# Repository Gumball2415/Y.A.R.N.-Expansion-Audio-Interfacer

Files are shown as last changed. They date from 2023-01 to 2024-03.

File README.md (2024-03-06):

# Y.A.R.N. Expansion Audio Interfacer

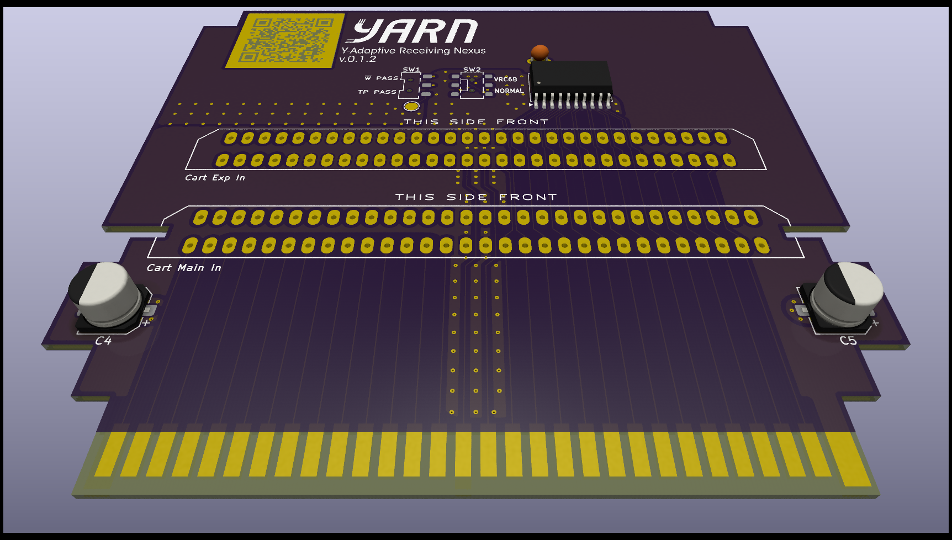
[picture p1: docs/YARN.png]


An Open-Source HardWare (OSHW) Famicom single expansion audio interfacer.

## About

This project aims to allow a host cartridge to control an expansion audio cartridge's sound chip through selected audio registers. This is a child of the S.C.A.R.F. project.

The principle is that the Main cartridge is expected to contain everything the NSF or program needs, with the audio solely being handled by the Exp audio cartridge.

This means that the expansion audio cartridge is write-only.

## Use

The Main cartridge is expected to contain mapper hardware that the NSF or program needs.

The Console is expected to not read the Exp. cartridge, but instead to write to registers the Exp. cartridge is expected to contain.

The Exp. cartridge must contain hardware that generates audio accessible by write-only registers that the Console expects.

If the Exp. cartridge contains VRC6B, toggle SW2 accordingly.

Do not toggle SW1, it is for prototyping purposes.

For Everdrives and flash carts: The flash cart UI (if it has one) may cause unwanted side effects if it is connected to YARN.

## PCB Specifications

- 2 layer PCB
- 1.2mm thickness
- ENIG-RoHS surface finish recommended; Gold fingers optional
- Beveled edge, chamfer cut
- Any soldermask color you want!

## License

- The PCB and schematics are licensed under the TAPR Open Hardware License ([www.tapr.org/OHL](http://www.tapr.org/OHL)).
- The S.C.A.R.F. Expansion Audio Interfacer Address Decoder ROM source code file is licensed under [MIT](https://mit-license.org/)
- © Persune 2022

## Credits

- lidnariq, grievre, Iyatemu, and plgDavid - advice, suggestions, general help
- lidnariq - providing advice for my schematics and addressing logic
- grievre - providing advice for my PCB design
- Special thanks to the NESDEV community, this project wouldn't have been possible without their extensive information and wiki!

## Support

If you enjoy this project or find it helpful, please support me on [Ko-Fi](https://ko-fi.com/persune) or [Patreon](https://www.patreon.com/persune)!

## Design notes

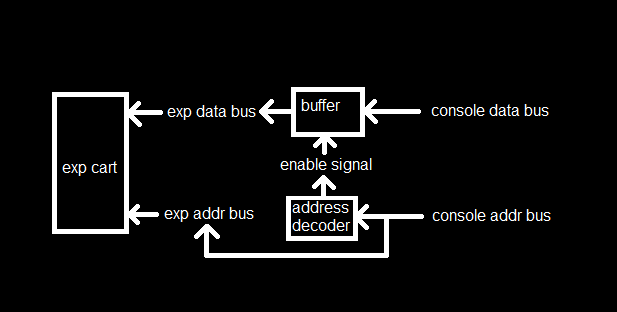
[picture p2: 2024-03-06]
docs/simplified schematics.png

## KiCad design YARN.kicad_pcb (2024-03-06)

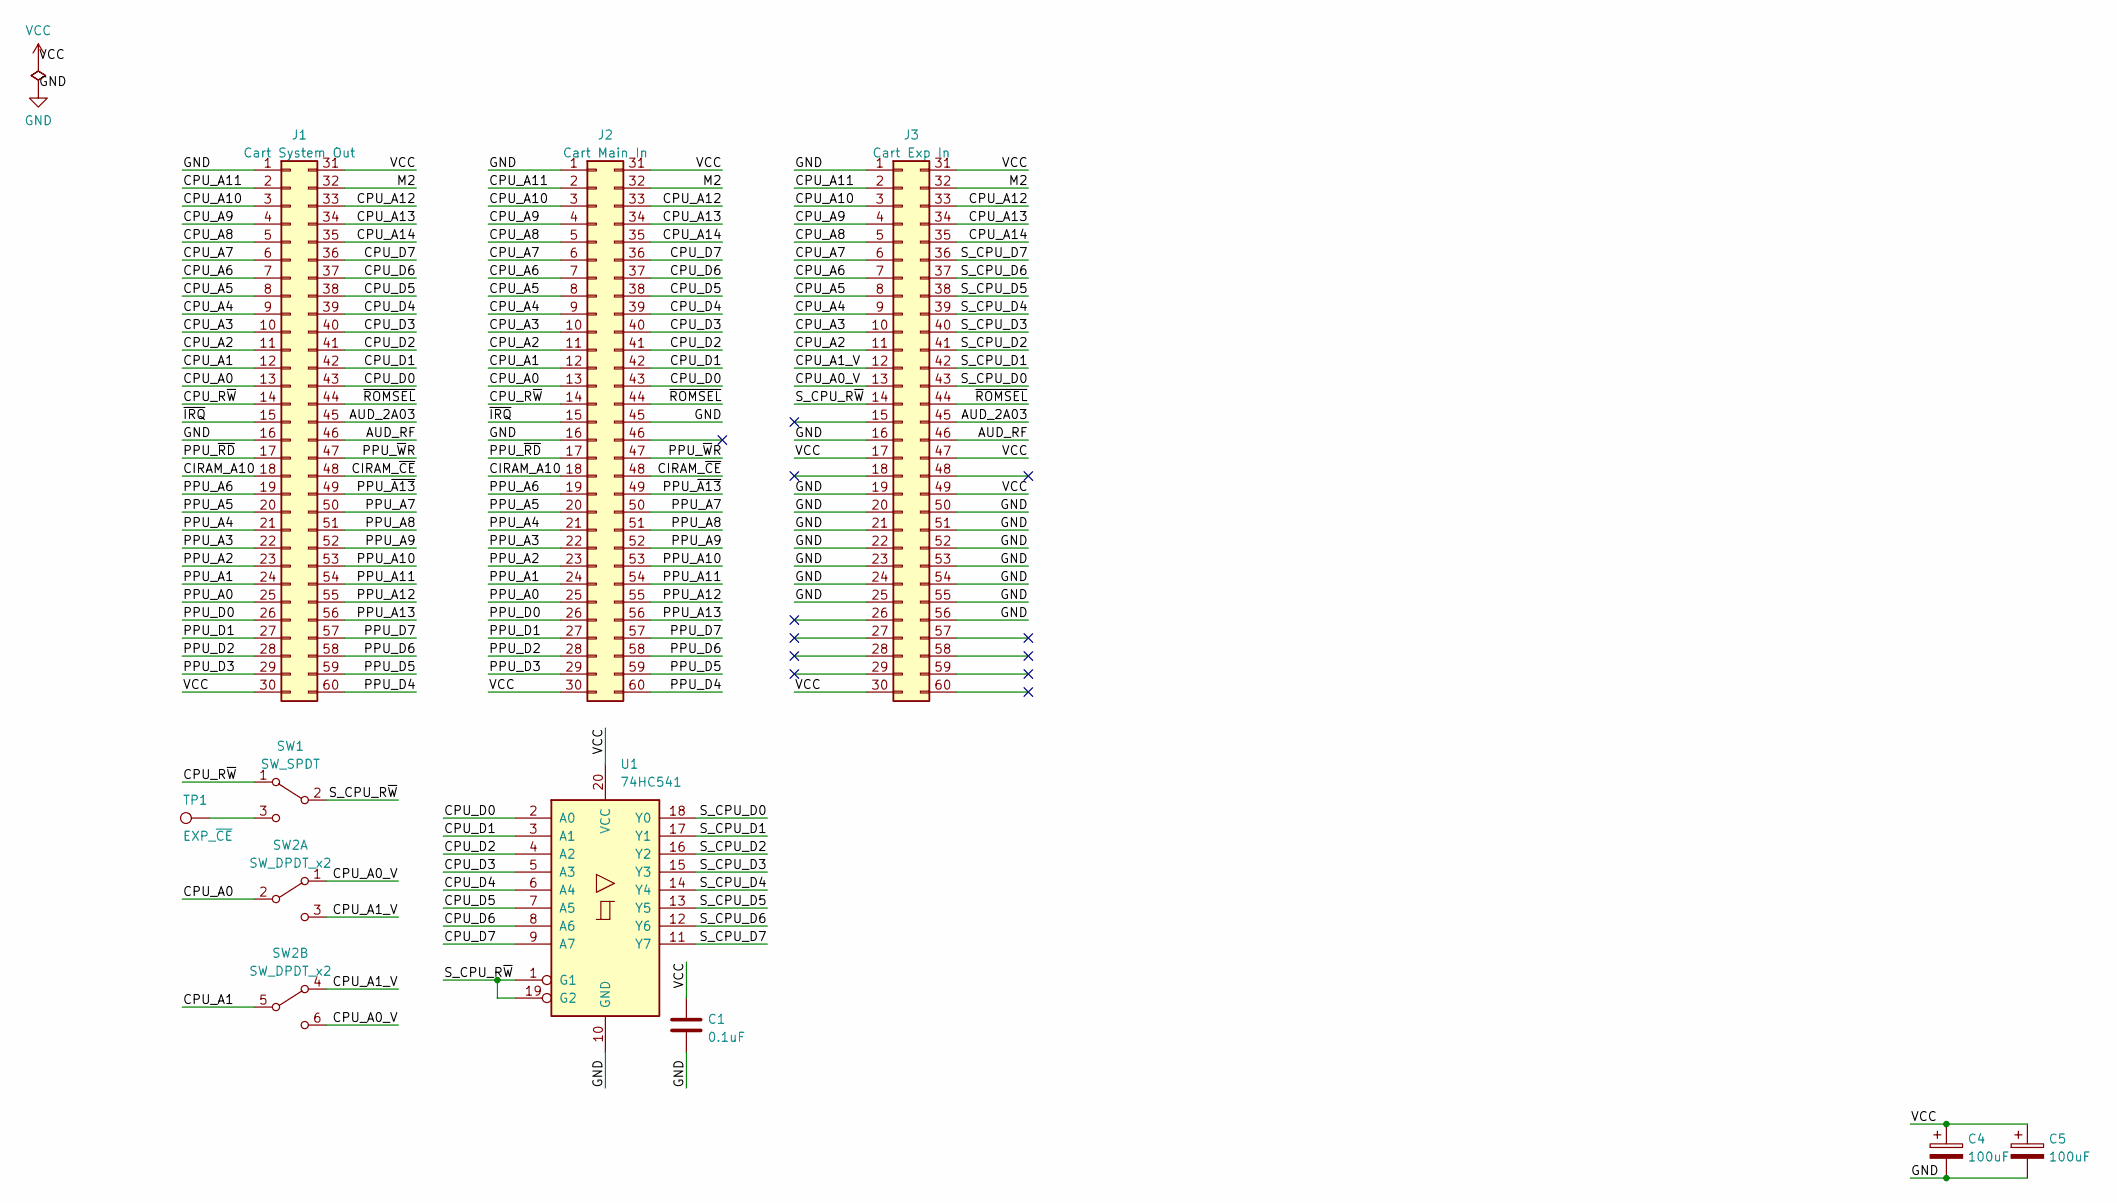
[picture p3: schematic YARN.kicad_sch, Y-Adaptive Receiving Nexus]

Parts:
C1: 0.1uF; C_Disc-0805_D3.0mm_W1.6mm_P2.50mm
C4, C5: 100uF; CP_Elec_6.3x5.4
J1: Cart System Out; HVC-ETROM-01
J2: Cart Main In; FC_CONN_F
J3: Cart Exp In; FC_CONN_F
SW1: SW_SPDT; SK-3390A-L0
SW2: SW_DPDT_x2; SS-3390S-L0
TP1: EXP_~{CE}; TestPoint_Pad_D2.0mm
U1: 74HC541; SOIC-20W_7.5x12.8mm_P1.27mm

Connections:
/AUD_2A03: J1.45, J3.45
/AUD_RF: J1.46, J3.46
/CIRAM_A10: J1.18, J2.18
/CIRAM_~CE: J1.48, J2.48
/CPU_A0: J1.13, J2.13, SW2.2 (B)
/CPU_A0_V: J3.13, SW2.1 (A), SW2.6 (C)
/CPU_A1: J1.12, J2.12, SW2.5 (B)
/CPU_A1_V: J3.12, SW2.3 (C), SW2.4 (A)
/CPU_A2: J1.11, J2.11, J3.11
/CPU_A3: J1.10, J2.10, J3.10
/CPU_A4: J1.9, J2.9, J3.9
/CPU_A5: J1.8, J2.8, J3.8
/CPU_A6: J1.7, J2.7, J3.7
/CPU_A7: J1.6, J2.6, J3.6
/CPU_A8: J1.5, J2.5, J3.5
/CPU_A9: J1.4, J2.4, J3.4
/CPU_A10: J1.3, J2.3, J3.3
/CPU_A11: J1.2, J2.2, J3.2
/CPU_A12: J1.33, J2.33, J3.33
/CPU_A13: J1.34, J2.34, J3.34
/CPU_A14: J1.35, J2.35, J3.35
/CPU_D0: J1.43, J2.43, U1.2 (A0)
/CPU_D1: J1.42, J2.42, U1.3 (A1)
/CPU_D2: J1.41, J2.41, U1.4 (A2)
/CPU_D3: J1.40, J2.40, U1.5 (A3)
/CPU_D4: J1.39, J2.39, U1.6 (A4)
/CPU_D5: J1.38, J2.38, U1.7 (A5)
/CPU_D6: J1.37, J2.37, U1.8 (A6)
/CPU_D7: J1.36, J2.36, U1.9 (A7)
/CPU_R~W: J1.14, J2.14, SW1.1 (A)
/M2: J1.32, J2.32, J3.32
/PPU_A0: J1.25, J2.25
/PPU_A1: J1.24, J2.24
/PPU_A2: J1.23, J2.23
/PPU_A3: J1.22, J2.22
/PPU_A4: J1.21, J2.21
/PPU_A5: J1.20, J2.20
/PPU_A6: J1.19, J2.19
/PPU_A7: J1.50, J2.50
/PPU_A8: J1.51, J2.51
/PPU_A9: J1.52, J2.52
/PPU_A10: J1.53, J2.53
/PPU_A11: J1.54, J2.54
/PPU_A12: J1.55, J2.55
/PPU_A13: J1.56, J2.56
/PPU_D0: J1.26, J2.26
/PPU_D1: J1.27, J2.27
/PPU_D2: J1.28, J2.28
/PPU_D3: J1.29, J2.29
/PPU_D4: J1.60, J2.60
/PPU_D5: J1.59, J2.59
/PPU_D6: J1.58, J2.58
/PPU_D7: J1.57, J2.57
/PPU_~A13: J1.49, J2.49
/PPU_~RD: J1.17, J2.17
/PPU_~WR: J1.47, J2.47
/S_CPU_D0: J3.43, U1.18 (Y0)
/S_CPU_D1: J3.42, U1.17 (Y1)
/S_CPU_D2: J3.41, U1.16 (Y2)
/S_CPU_D3: J3.40, U1.15 (Y3)
/S_CPU_D4: J3.39, U1.14 (Y4)
/S_CPU_D5: J3.38, U1.13 (Y5)
/S_CPU_D6: J3.37, U1.12 (Y6)
/S_CPU_D7: J3.36, U1.11 (Y7)
/S_CPU_R~W: J3.14, SW1.2 (B), U1.1 (G1), U1.19 (G2)
/~IRQ: J1.15, J2.15
/~ROMSEL: J1.44, J2.44, J3.44
GND: C1.2, C4.2, C5.2, J1.1, J1.16, J2.1, J2.16, J2.45, J3.1, J3.16, J3.19, J3.20, J3.21, J3.22, J3.23, J3.24, J3.25, J3.50, J3.51, J3.52, J3.53, J3.54, J3.55, J3.56, U1.10 (GND)
unnamed: SW1.3 (C), TP1.1
VCC: C1.1, C4.1, C5.1, J1.30, J1.31, J2.30, J2.31, J3.17, J3.30, J3.31, J3.47, J3.49, U1.20 (VCC)

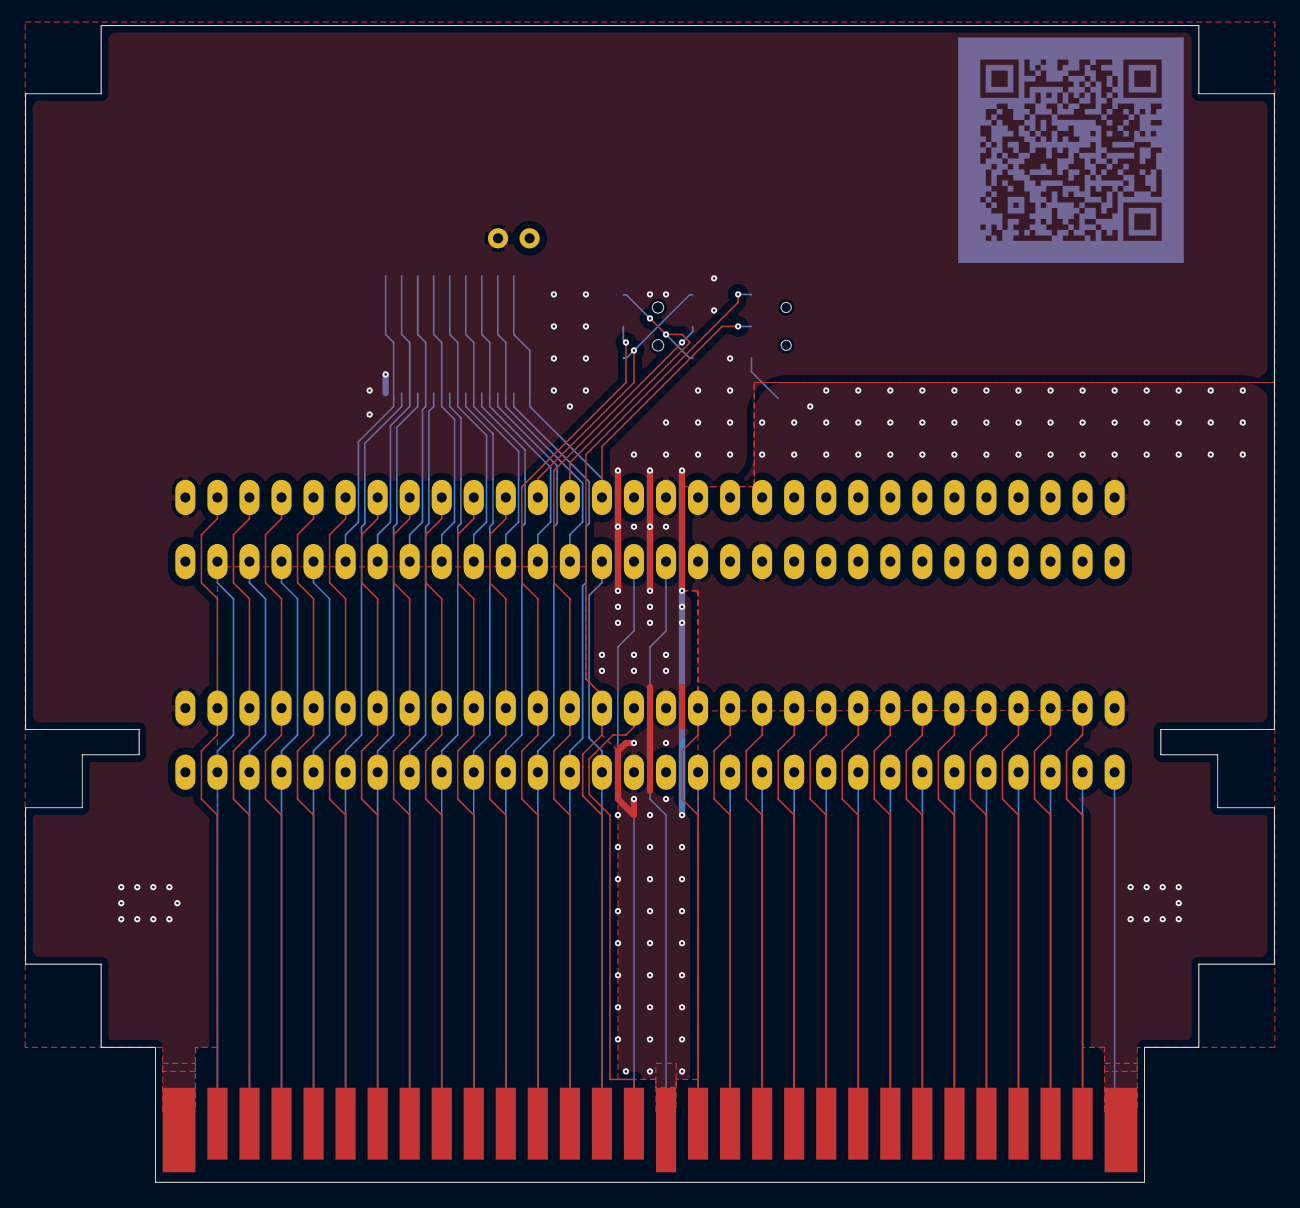
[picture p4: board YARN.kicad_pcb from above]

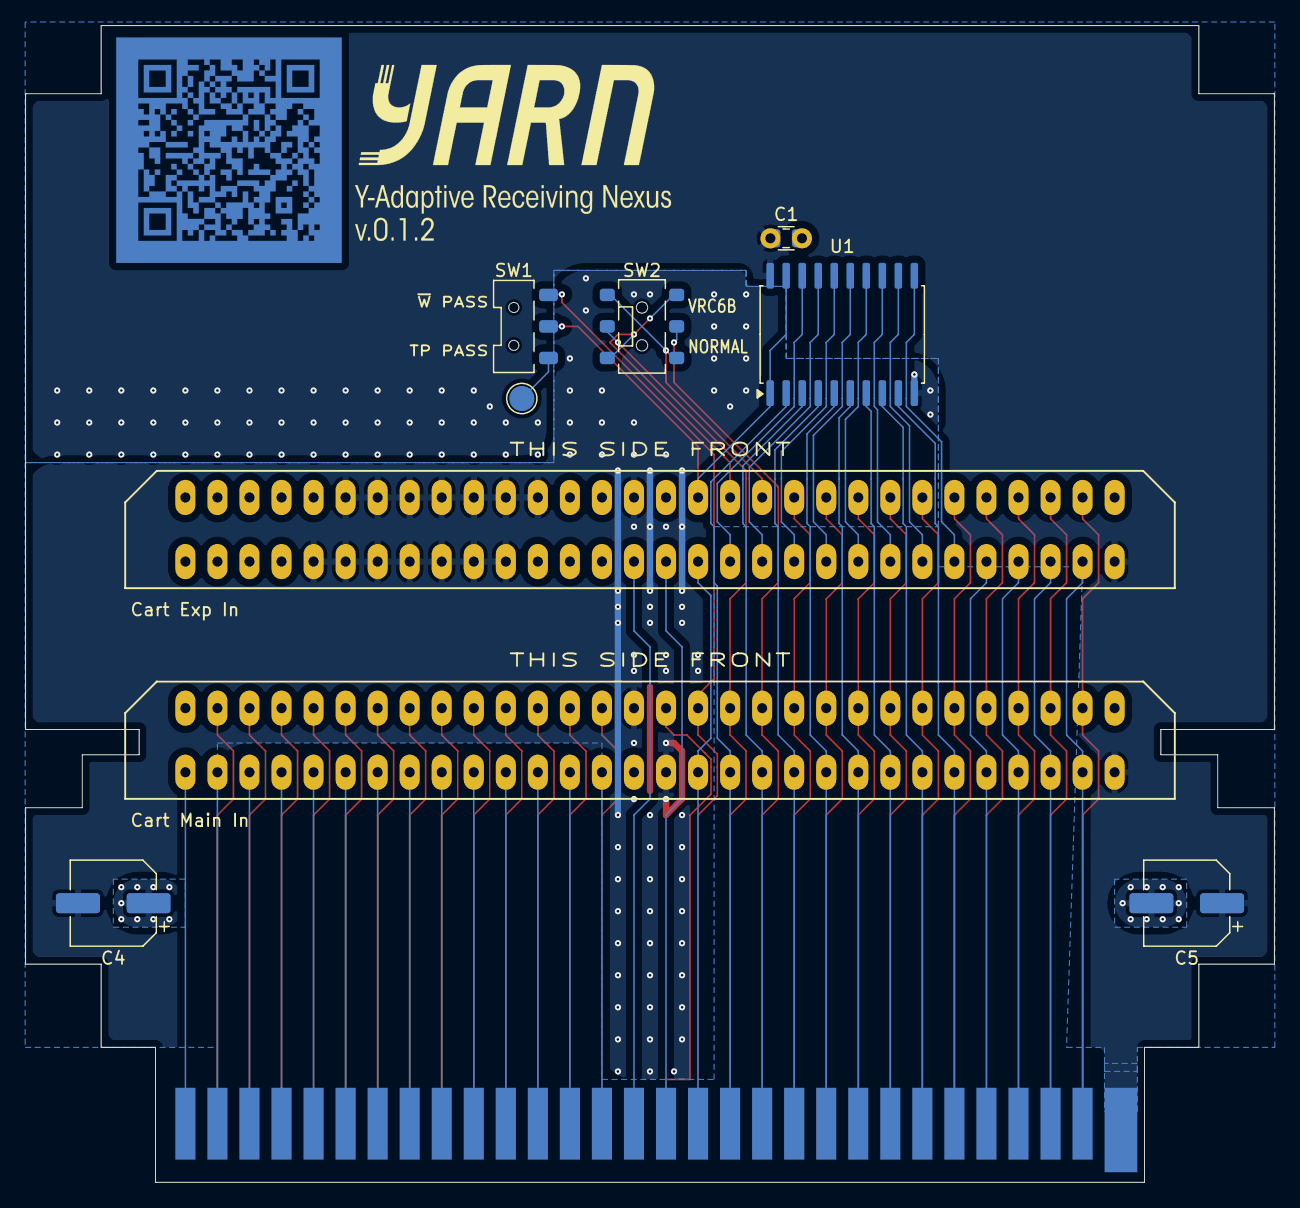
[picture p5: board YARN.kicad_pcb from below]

Board: 2 copper layers, 99.0 x 91.7 mm, 11 parts (10 on the bottom side), 70 nets.

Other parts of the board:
LOGO-2: YARN; YARN logo

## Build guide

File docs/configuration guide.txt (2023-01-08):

Terminate when no connection is specified:
	- bridge pad 1 and 2 on 3-pad jumpers
	- leave 2-pad jumpers disconnected

VRC6:		10xx 0000 0000 00xx
	Audio registers:
		$9003	     W
		$9000-$9002	 W
		$A000-$A002	 W
		$B000-$B002	 W

	Configuration (VRC6A):
		- CPU_A0 -> S_CPU_A0 (2-3)
		- CPU_A1 -> S_CPU_A1 (2-3)
		- CPU_A12 -> S_CPU_A12
		- CPU_A13 -> S_CPU_A13
		- ~{CE}_VRC6 -> S_~{ROMSEL}

	Configuration (VRC6B):
		- CPU_A3 -> S_CPU_A3 (1-3)
		- CPU_A4 -> S_CPU_A4 (1-3)
		- CPU_A5 -> S_CPU_A5
		- ~{CE}_VRC7 -> ~{ROMSEL}

VRC7:		1xxx 0000 00x1 0000
	Audio registers:
		$9010		     W
		$9030		     W
		$E000		     W

	Configuration:
		- CPU_A4 -> S_CPU_A4
		- CPU_A5 -> S_CPU_A5
		- ~{CE}_VRC7 -> S_~{ROMSEL}

Sunsoft 5B:	11xx xxxx xxxx xxxx
	Audio registers:
		$C000-$DFFF	 W
		$E000-$FFFF	 W

	Configuration:
		- CPU_A13 -> S_CPU_A13
		- CPU_A14 -> S_CPU_A14
		- ~{CE}_S5B -> S_~{ROMSEL}

N163:		x1xx xxxx xxxx xxxx
	Audio registers:
		$4800-$4FFF	RW
		$E000-$E7FF	 W
		$F800-$FFFF	RW

	Configuration:
		- CPU_A11 -> S_CPU_A11
		- CPU_A12 -> S_CPU_A12
		- CPU_A13 -> S_CPU_A13
		- CPU_A14  -> S_CPU_A14
		- CPU_R~{W) -> S_CPU_R~{W}
		- ~{ROMSEL} -> S_~{ROMSEL}

MMC5:		0101 xxxx xxxx xxxx
	Audio registers:
		$5000-$5007	 W
		$5010         RW
		$5011          W
		$5015         RW
		$5205-$5206   RW      MMC5 multiplier
		$5C00-$5FF5   RW      MMC5 internal extended RAM

	Configuration:
		- CPU_A0 -> S_CPU_A0
		- CPU_A1 -> S_CPU_A1
		- CPU_A2 -> S_CPU_A2
		- CPU_A3 -> S_CPU_A3
		- CPU_A4 -> S_CPU_A4
		- CPU_A5 -> S_CPU_A5
		- CPU_A6 -> S_CPU_A6
		- CPU_A7 -> S_CPU_A7
		- CPU_A8 -> S_CPU_A8
		- CPU_A9 -> S_CPU_A9
		- CPU_A10 -> S_CPU_A10
		- CPU_A11 -> S_CPU_A11
		- CPU_A12 -> S_CPU_A12
		- CPU_A14 -> S_CPU_A14
		- CPU_R~{W) -> S_CPU_R~{W}
		- ~{ROMSEL} -> S_~{ROMSEL}

FDS:		0100 0000 xxxx xxxx
	Audio registers:
		$4023         ?
		$4040-$4080   RW
		$4082-$408A    W
		$4090-$4097   R

	Configuration:
		- CPU_A0 -> S_CPU_A0
		- CPU_A1 -> S_CPU_A1
		- CPU_A2 -> S_CPU_A2
		- CPU_A3 -> S_CPU_A3
		- CPU_A4 -> S_CPU_A4
		- CPU_A5 -> S_CPU_A5
		- CPU_A6 -> S_CPU_A6
		- CPU_A7 -> S_CPU_A7
		- ~{CE}_FDS -> S_CPU_A12
		- CPU_A14 -> S_CPU_A14
		- CPU_R~{W) -> S_CPU_R~{W}

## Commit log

2022-11-13 Version 0.0.1
    [YARN.kicad_pcb, YARN.kicad_sch]
2022-11-14 Fix copper fills
    [YARN.kicad_pcb, YARN.kicad_sch]
2023-01-08 Use bus buffers instead of decoding logic
    [YARN-rounded.kicad_pcb, YARN.kicad_sch]
2023-03-01 Buffer data and addr bus, add switch for VRC6 A/B
    [YARN-rounded.kicad_pcb, YARN.kicad_pcb, YARN.kicad_sch]
2023-03-05 Improve slide switch footprints
    [YARN-rounded.kicad_pcb, YARN.kicad_pcb, YARN.kicad_sch]
2023-03-05 SS-3390S-L0 has slightly different dimensions
    [YARN-rounded.kicad_pcb, YARN.kicad_pcb]
2024-03-06 Redesign decoding architecture
    Thanks, lidnariq and Perkka!
    [YARN-rounded.kicad_pcb, YARN.kicad_pcb, YARN.kicad_sch]
